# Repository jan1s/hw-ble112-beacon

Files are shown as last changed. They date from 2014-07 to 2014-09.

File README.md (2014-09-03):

hw-ble112-beacon
================

This is a minimal beacon pcb for the BLE112 module.

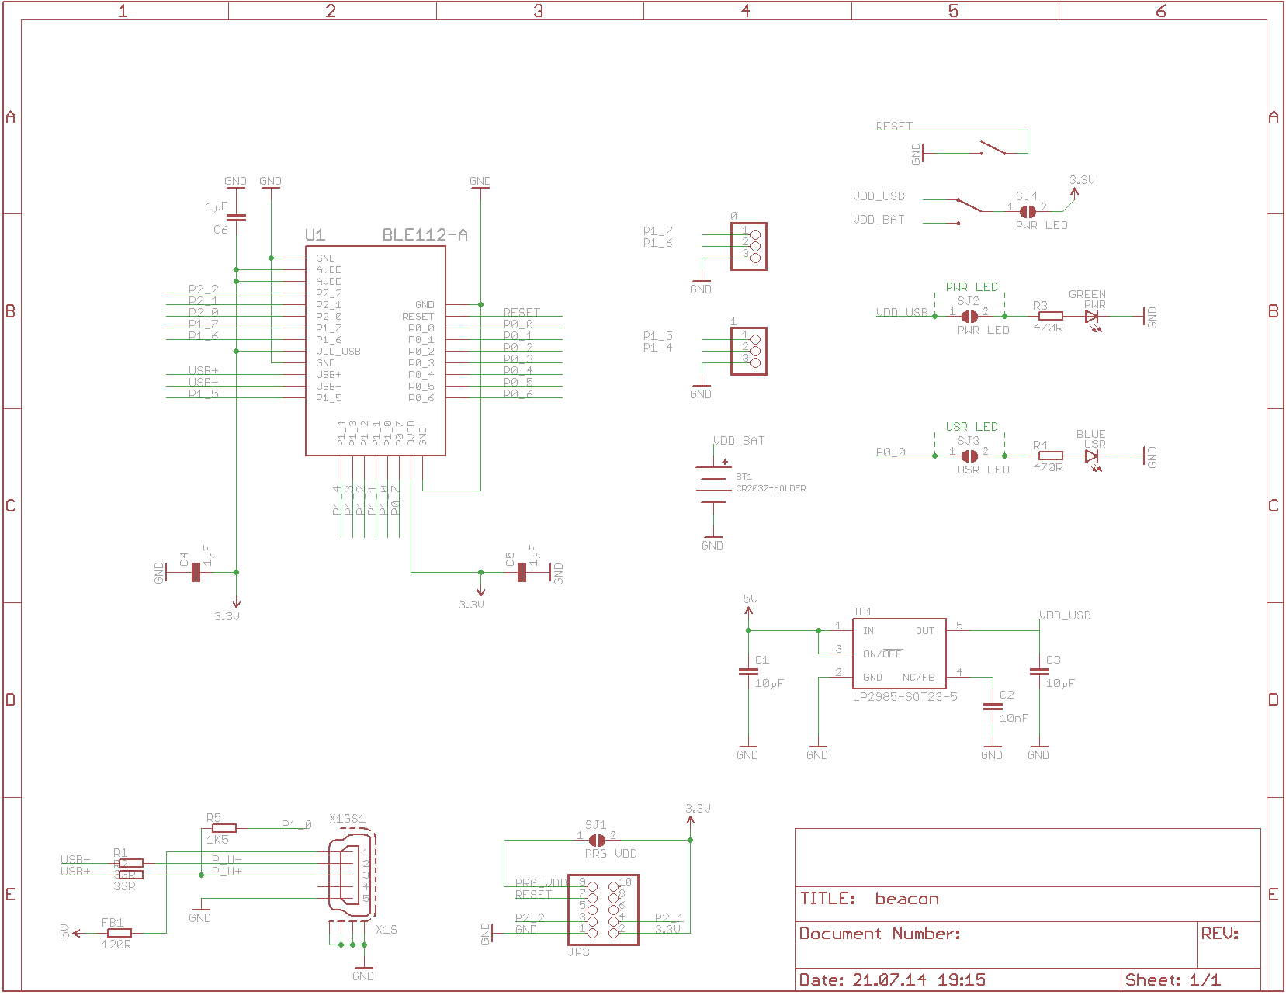
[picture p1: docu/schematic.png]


Project schematic, the same for both versions.

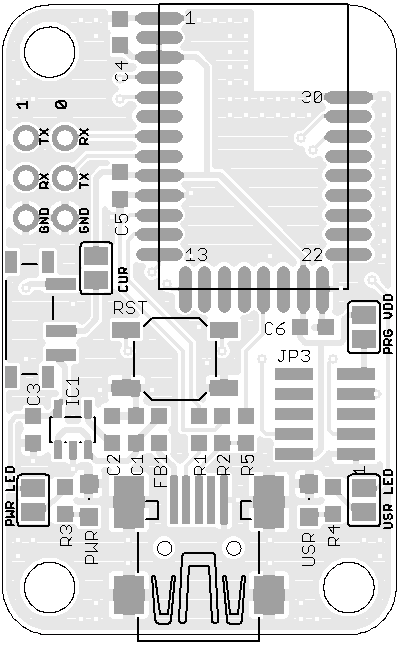
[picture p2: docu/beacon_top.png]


Render for the uncased version from [DirtyPCB][dirtypcb].

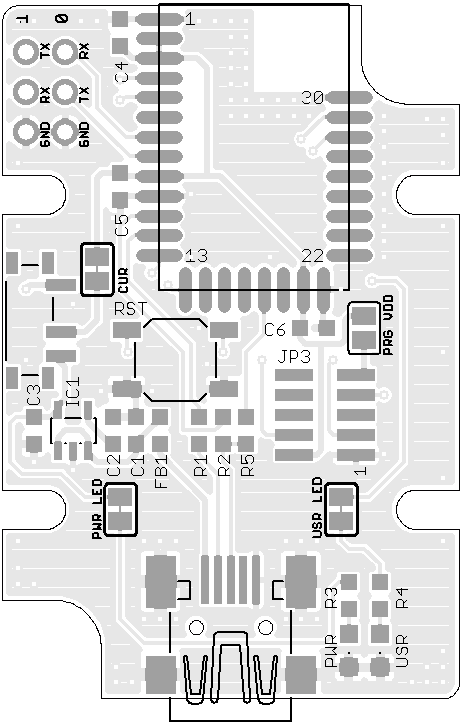
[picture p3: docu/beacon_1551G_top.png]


Render for the cased version from [DirtyPCB][dirtypcb].

## BOM
| Identifier | Type/Value | Quantity | Comment | Supplier Id | Supplier |
| --- | --- | --- | --- | --- | --- |
| R1, R2 | 33 Ω | 2 |  | SMD-0603 33  | [Reichelt][reichelt] |
| R3, R4 | 470 Ω | 2 |  | SMD-0603 470 | [Reichelt][reichelt] |
| R5 | 1 kΩ | 2 |  | SMD-0603 1K5 | [Reichelt][reichelt] |
| C2 | 10 nF | 1 |  | X7R-G0603 10N | [Reichelt][reichelt] |
| C1, C3-C6 | 10 µF | 6 |  | X5R-G0603 10/6 | [Reichelt][reichelt] |
| U1 | BLE112 | 1 |  | 603-BLE112-A | [Mouser][mouser] |
| IC1 | LP2985 | 1 |  | LP 2985 IM5-3,3 | [Reichelt][reichelt] |
| X1S | USB Jack | 1 |  | USB BWM SMD | [Reichelt][reichelt] |
| JP3 | 2x5 1.27 | 1 |  | 649-202112100010C4LF | [Mouser][mouser] |
| BT1 | Batteryholder | 1 |  | KZH 20SMD-2 | [Reichelt][reichelt] |
| SW1 | Switch | 1 |  | 1P2T ON-ON type SMD mini slide switch | [Aliexpress][aliexpress] |

[reichelt]: http://www.reichelt.de
[mouser]: http://mouser.com
[aliexpress]: http://www.aliexpress.com

[dirtypcb]: http://dirtypcbs.com
[itead-pcb]: http://imall.iteadstudio.com/open-pcb/pcb-prototyping.html

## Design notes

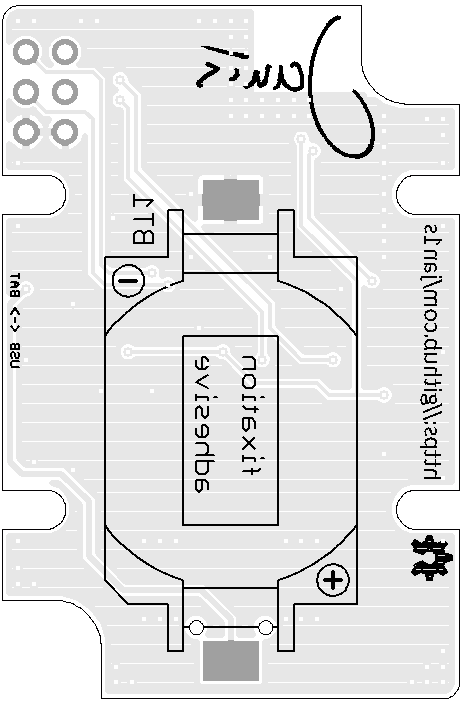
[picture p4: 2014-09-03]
docu/beacon_1551G_bottom.png

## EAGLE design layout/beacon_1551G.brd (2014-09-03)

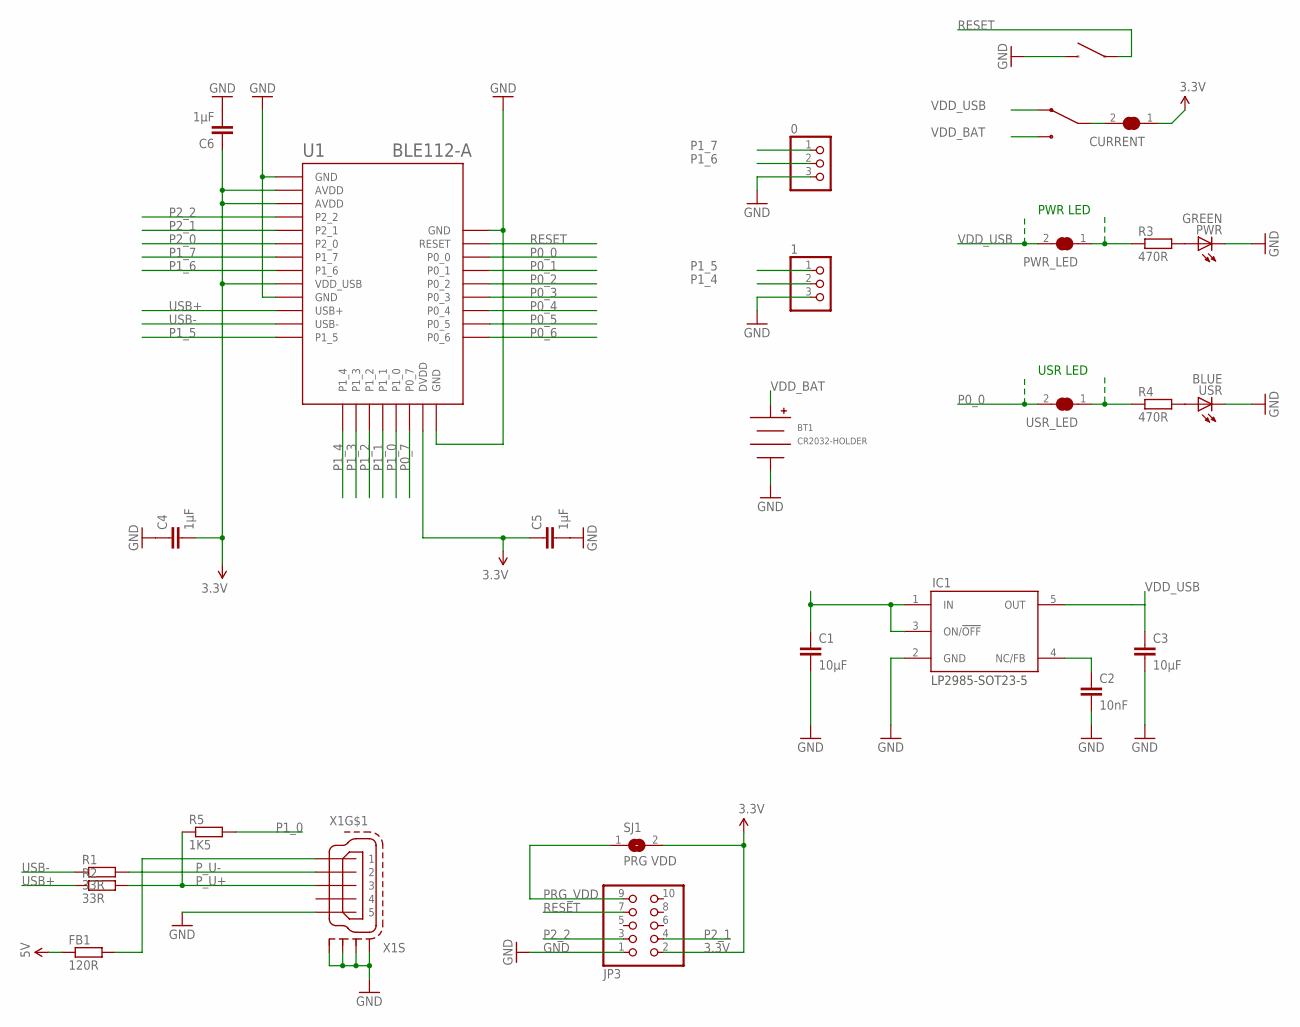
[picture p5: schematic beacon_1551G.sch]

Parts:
0, 1: HEADER-1X3ROUND; 1X03_ROUND
BT1: CR2032-HOLDER; CH28-2032LF
C1, C3: 10µF; C0603
C2: 10nF; C0603
C4, C5, C6: 1µF; C0603
CURRENT: SOLDERJUMPER_CLOSED; SOLDERJUMPER_CLOSEDWIRE
FB1: 120R; R0603
IC1: LP2985-SOT23-5; SOT23-5
JP3: ARM-JTAG_1.27-SMD; 20021121-10010XXLF
PWR: GREEN; CHIPLED_0805
PWR_LED: SOLDERJUMPER_CLOSED; SOLDERJUMPER_CLOSEDWIRE
R1, R2: 33R; R0603
R3, R4: 470R; R0603
R5: 1K5; R0603
RST: TACT-SWITCH-40-40; 40-40
SJ1: PRG VDD; SJ
U1: BLE112-A
U$1: 1P2T; 1P2T-ON-ON
USR: BLUE; CHIPLED_0805
USR_LED: SOLDERJUMPER_CLOSED; SOLDERJUMPER_CLOSEDWIRE
X1: MINI-USB-SCHIELD-32005-301; 32005-301

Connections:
3.3V: C4.2, C5.1, C6.1, CURRENT.1, JP3.2, SJ1.2, U1.AVDD1 (AVDD), U1.AVDD2 (AVDD), U1.DVDD, U1.VDD_USB
GND: 0.3, 1.3, BT1.NEG, C1.2, C2.2, C3.2, C4.1, C5.2, C6.2, IC1.2 (GND), JP3.1, PWR.C, RST.1, RST.2, U1.GND1 (GND), U1.GND2 (GND), U1.GND3 (GND), U1.GND4 (GND), USR.C, X1.5, X1.M1 (S1), X1.M2 (S2), X1.M3 (S3), X1.M4 (S4)
unnamed: PWR.A, R3.2
unnamed: R4.2, USR.A
unnamed: PWR_LED.1, R3.1
unnamed: CURRENT.2, U$1.2
unnamed: R4.1, USR_LED.1
unnamed: C2.1, IC1.4 (NC/FB)
P0_0: U1.P0_0, USR_LED.2
P0_1: U1.P0_1
P0_2: U1.P0_2
P0_3: U1.P0_3
P0_4: U1.P0_4
P0_5: U1.P0_5
P0_6: U1.P0_6
P0_7: U1.P0_7
P1_0: R5.2, U1.P1_0
P1_1: U1.P1_1
P1_2: U1.P1_2
P1_3: U1.P1_3
P1_4: 1.2, U1.P1_4
P1_5: 1.1, U1.P1_5
P1_6: 0.2, U1.P1_6
P1_7: 0.1, U1.P1_7
P2_0: U1.P2_0
P2_1: JP3.4, U1.P2_1
P2_2: JP3.3, U1.P2_2
PRG_VDD: JP3.9, SJ1.1
P_U+: R2.2, R5.1, X1.3
P_U-: R1.2, X1.2
RESET: JP3.7, RST.3, RST.4, U1.RESET
USB+: R2.1, U1.USB+
USB-: R1.1, U1.USB-
VBUS: FB1.2, X1.1
VDD_BAT: BT1.POS, U$1.3
VDD_USB: C3.1, IC1.5 (OUT), PWR_LED.2, U$1.1

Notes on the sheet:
PWR LED
USR LED

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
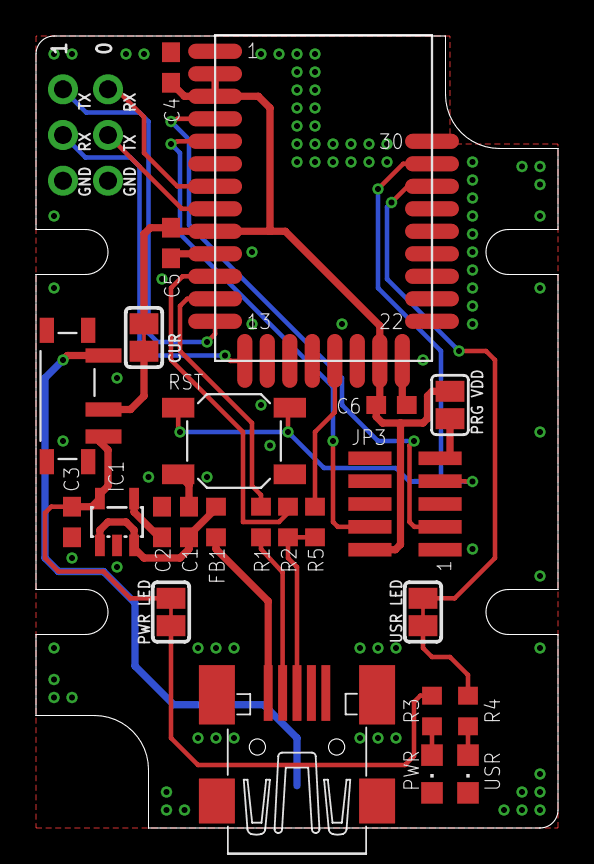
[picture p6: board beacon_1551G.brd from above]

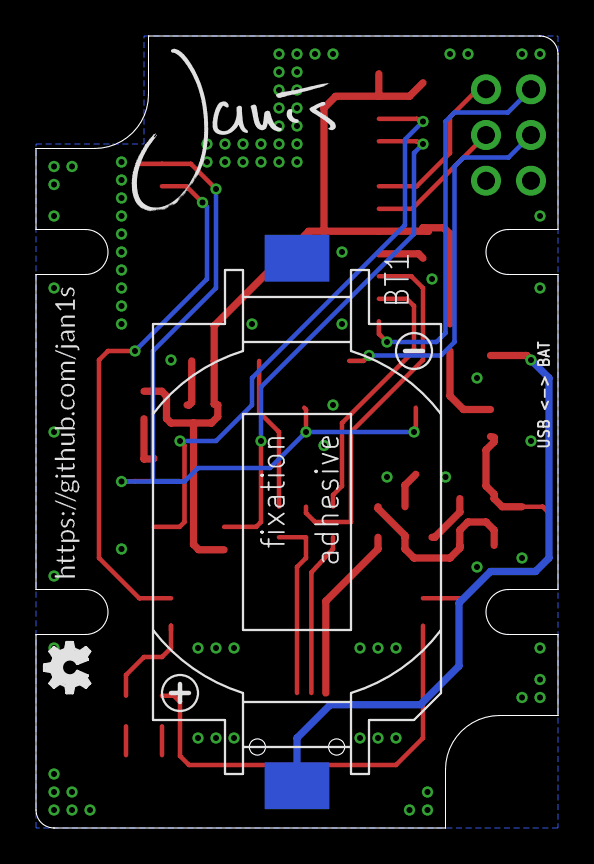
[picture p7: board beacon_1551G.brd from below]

Board: 2 copper layers, 29.0 x 44.0 mm, 30 parts (4 on the bottom side), 26 nets.

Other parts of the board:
U$2: JANIS_10MM
U$4: GITHUB/JAN1S
U$5: OSHW_FILLX100_NOTEXT

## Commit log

2014-07-21 Added battery option
    [beacon.brd, beacon.sch]
2014-07-21 Added production files
    [beacon.GBL, beacon.GBO, beacon.GBS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]
2014-07-21 Minor fix
    [beacon.brd, beacon.sch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]
2014-09-03 Added 1551G version
    [beacon_1551G.brd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]
2014-09-03 Added docu schematic

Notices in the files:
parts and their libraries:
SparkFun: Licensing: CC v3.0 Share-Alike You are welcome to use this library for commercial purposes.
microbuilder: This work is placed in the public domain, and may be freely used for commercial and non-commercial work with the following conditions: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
